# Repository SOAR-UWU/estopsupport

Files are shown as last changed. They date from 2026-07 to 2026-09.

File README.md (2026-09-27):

# Emergency-Stop Support Circuit
Driver Circuit for a Kilovac EV200 Contactor.
Takes two switch inputs which are expected to run at 5V with low current.

Theoretically, this can accept any relay or contactor that:
- has sufficiently high coil voltage, matched to the battery input, or uses a coil economiser
- has in-built back-emf suppression

# Variant: Integrated Automotive Relay
See relay branch for details - board designed to consolidate parts for the sake of compactness.

# Expected Operating Range

| Name | Value | Unit |
| --- | --- | ---- |
| Battery Voltage | 12 - 16.8 | V |
| Battery Current | ≤ 3 | A |
| Signal Voltage  | 5 | V |
| Signal Current  | 0 - 1 | A |
| Tap Voltage | 3.3 | V |
| Tap Current | 1.5 | A |
| Sense Resistor Voltage | 0.33 | V |
| Sense Resistor Voltage (Fault) | 5.2 | V |

# [BTS6163D PROFET](https://www.infineon.com/assets/row/public/documents/10/49/infineon-bts6163d-ds-en.pdf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)
This circuit is primarily based on the BTS6163 PROFET, which behaves like a P-type MOSFET.
It is chosen due to the fault protection capabilities - it will fail open.

## Sense Resistor
There is a 1 kOhm resistor on the right side of the board that indicates whether the BTS6163D PROFET is in a fault condition.
Fault conditions generally include: Short circuit, overtemperature, overload.

# Opto-isolation
The 5V Signal side (left) is opto-isolated from the Battery Voltage side (right).
Opto-coupler was chosen over a MOSFET such that the 5V side can control the higher voltage side without a risk of shorting battery voltage (16.8V) to the 5V rail.

# Split ground planes
If separate power sources are used for 5V and Battery, both sides will be totally decoupled.
This reduces electromagnetic interference - but is not important in this circuit, as it does not work with sensitive signals.

# Order Parameters
Material: FR-4
Layers: 2
Copper Weight: 1 oz

# Recommended Wiring
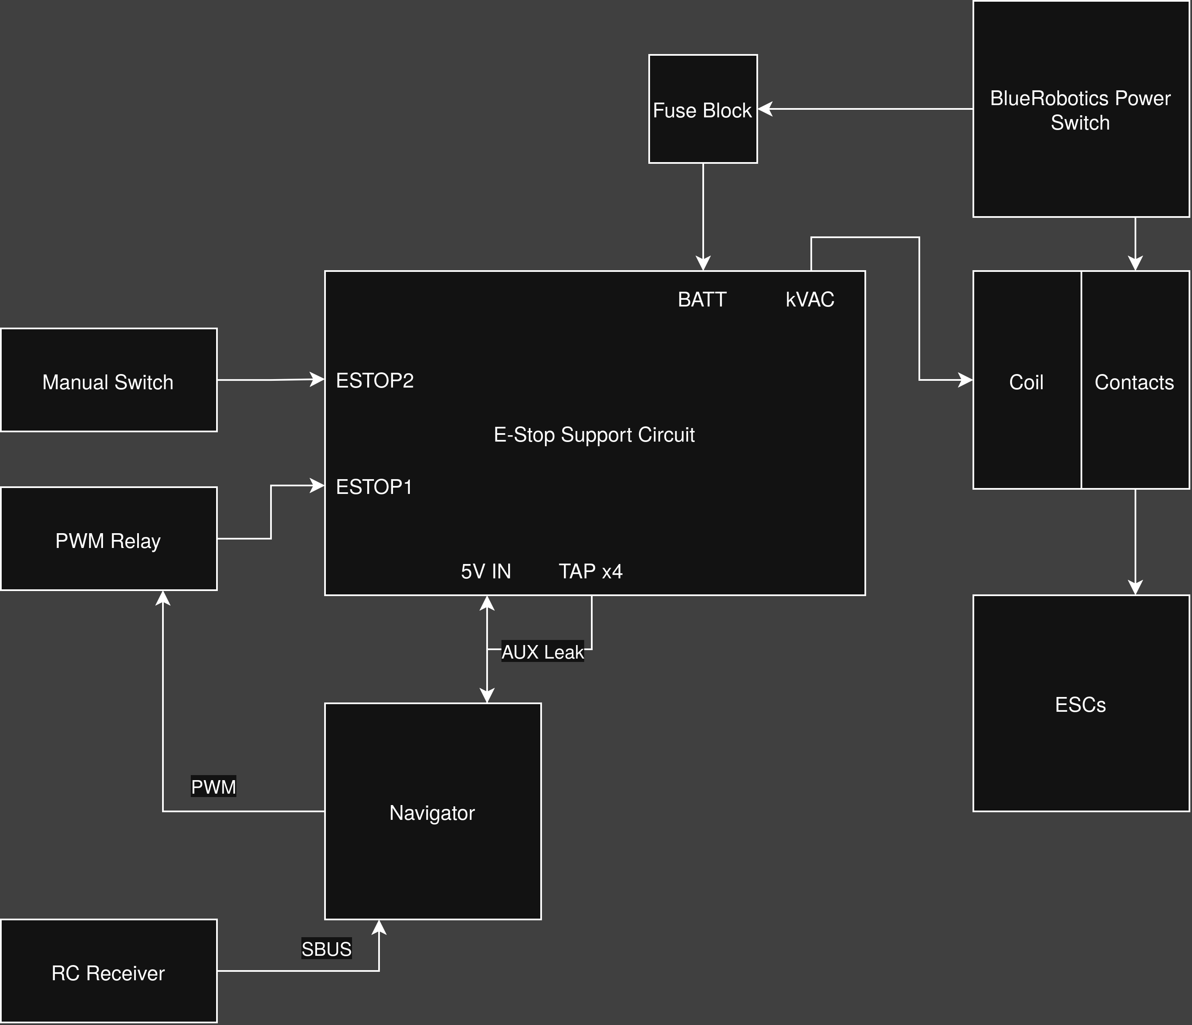
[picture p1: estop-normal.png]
normal

Normal Operation

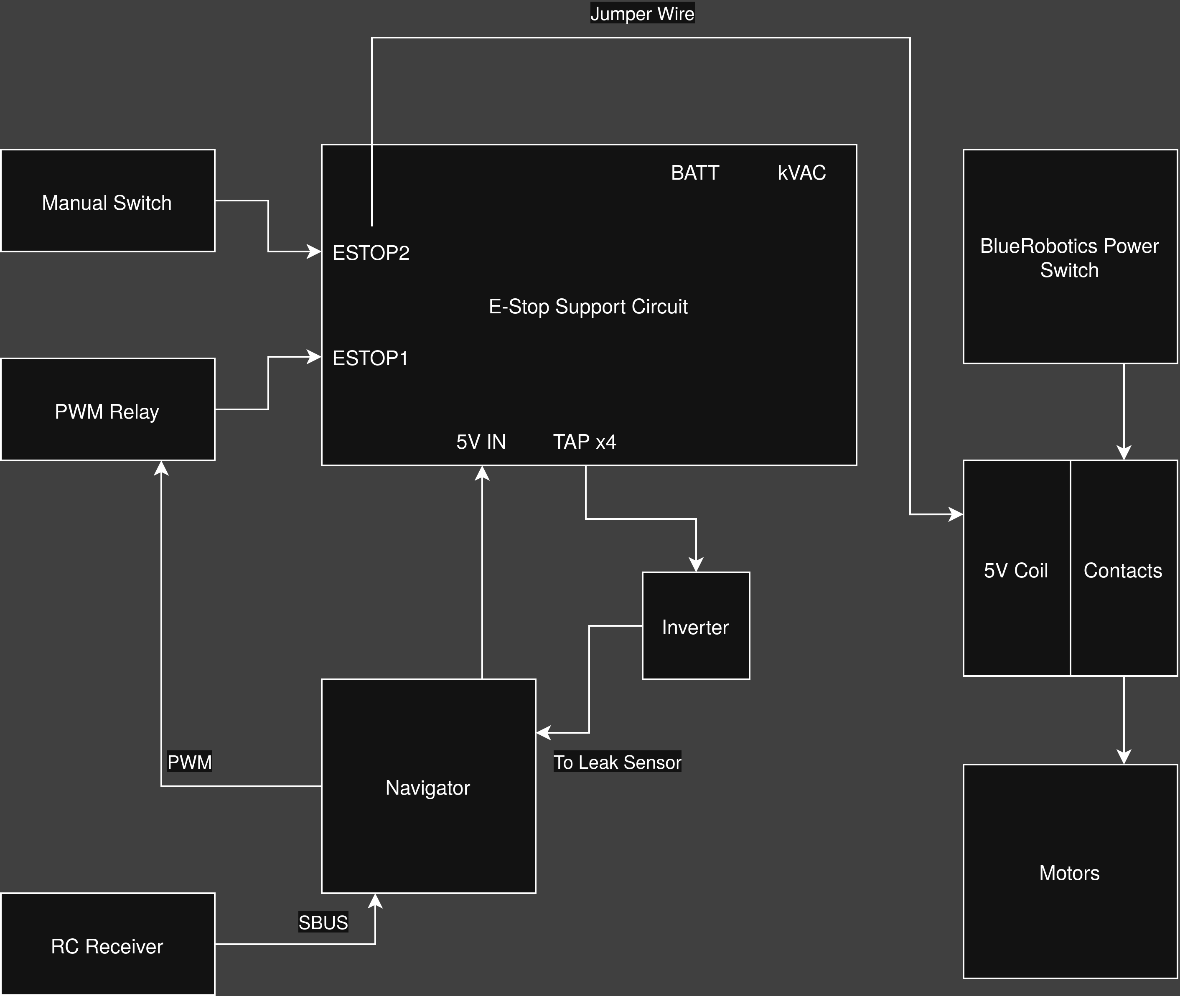
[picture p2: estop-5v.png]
5v

5V Relay Control

Battery voltage side is not used. This is because the PROFET has a threshold voltage of 5.5V.

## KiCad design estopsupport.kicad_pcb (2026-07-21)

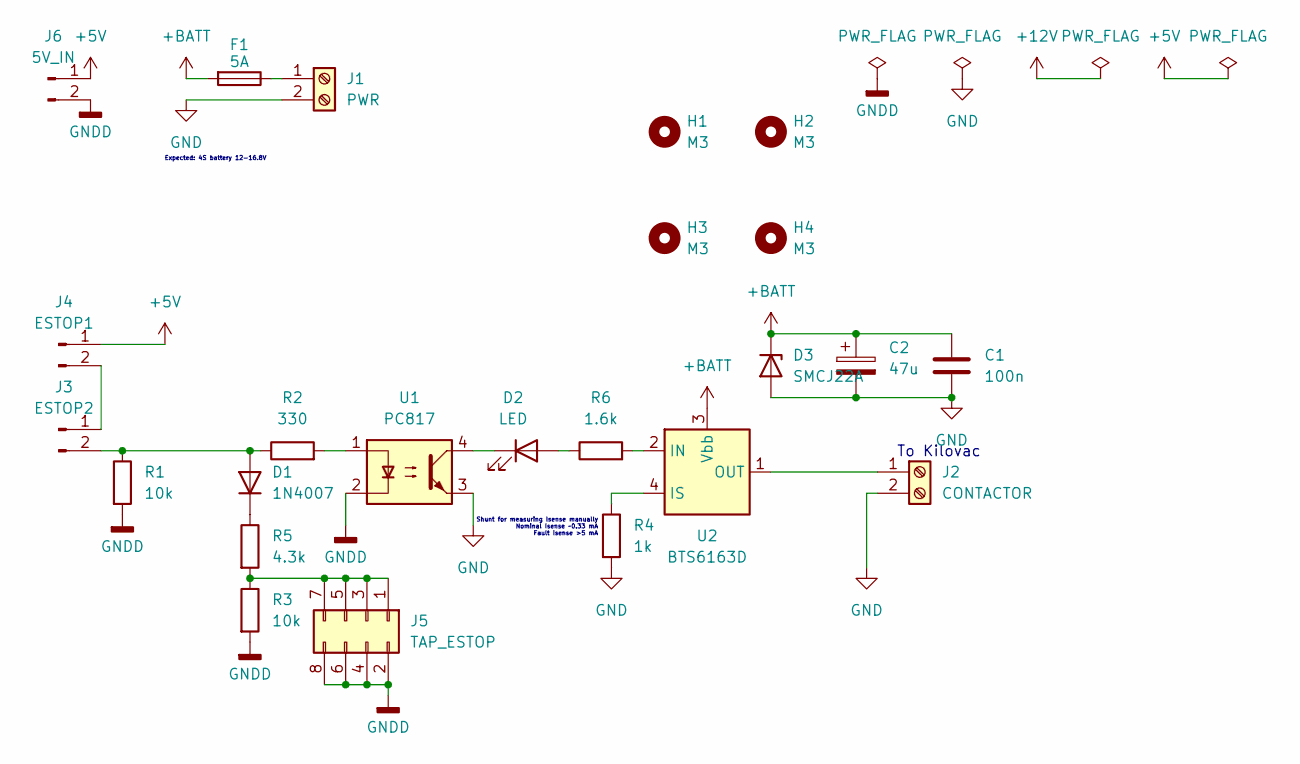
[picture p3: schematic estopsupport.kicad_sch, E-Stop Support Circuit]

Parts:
C1: 100n; C_1206_3216Metric; JLCPCB Part # C24497
C2: 47u; CP_Elec_6.3x5.4; JLCPCB Part # C48543040
D1: 1N4007; D_SMA; JLCPCB Part # C2909831
D2: LED; LED_D3.0mm
D3: SMCJ22A; D_SMC
F1: 5A; Fuse_1206_3216Metric_Pad1.42x1.75mm_HandSolder
H1, H2, H3, H4: M3; MountingHole_3.2mm_M3
J1: PWR; TerminalBlock_Phoenix_MKDS-1,5-2_1x02_P5.00mm_Horizontal
J2: CONTACTOR; TerminalBlock_Phoenix_MKDS-1,5-2_1x02_P5.00mm_Horizontal
J3: ESTOP2; PinHeader_1x02_P2.54mm_Horizontal
J4: ESTOP1; PinHeader_1x02_P2.54mm_Horizontal
J5: TAP_ESTOP; PinSocket_2x04_P2.54mm_Horizontal
J6: 5V_IN; PinHeader_1x02_P2.54mm_Horizontal
R1, R3: 10k; R_0603_1608Metric
R2: 330; R_0603_1608Metric
R4: 1k; R_Axial_DIN0204_L3.6mm_D1.6mm_P7.62mm_Horizontal
R5: 4.3k; R_0603_1608Metric
R6: 1.6k; R_0603_1608Metric
U1: PC817; DIP-4_W7.62mm; JLCPCB Part # C5350
U2: BTS6163D; TO-252-4; JLCPCB Part # C534821

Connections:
+5V: J4.1, J6.1
+BATT: C1.1, C2.1, D3.1 (K), F1.2, U2.3 (Vbb)
GND: C1.2, C2.2, D3.2 (A), J1.2, J2.2, R4.2, U1.3
GNDD: J5.2, J5.4, J5.6, J5.8, J6.2, R1.2, R3.2, U1.2
unnamed: D1.2 (A), J3.2, R1.1, R2.1
unnamed: D1.1 (K), R5.1
unnamed: D2.2 (A), R6.1
unnamed: D2.1 (K), U1.4
unnamed: F1.1, J1.1
unnamed: J2.1, U2.1 (OUT), U2.5 (OUT)
unnamed: J3.1, J4.2
unnamed: J5.1, J5.3, J5.5, J5.7, R3.1, R5.2
unnamed: R2.2, U1.1
unnamed: R6.2, U2.2 (IN)
unnamed: R4.1, U2.4 (IS)

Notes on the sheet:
Shunt for measuring Isense manually Nominal Isense ~0.33 mA Fault Isense >5 mA
To Kilovac
Expected: 4S battery 12-16.8V

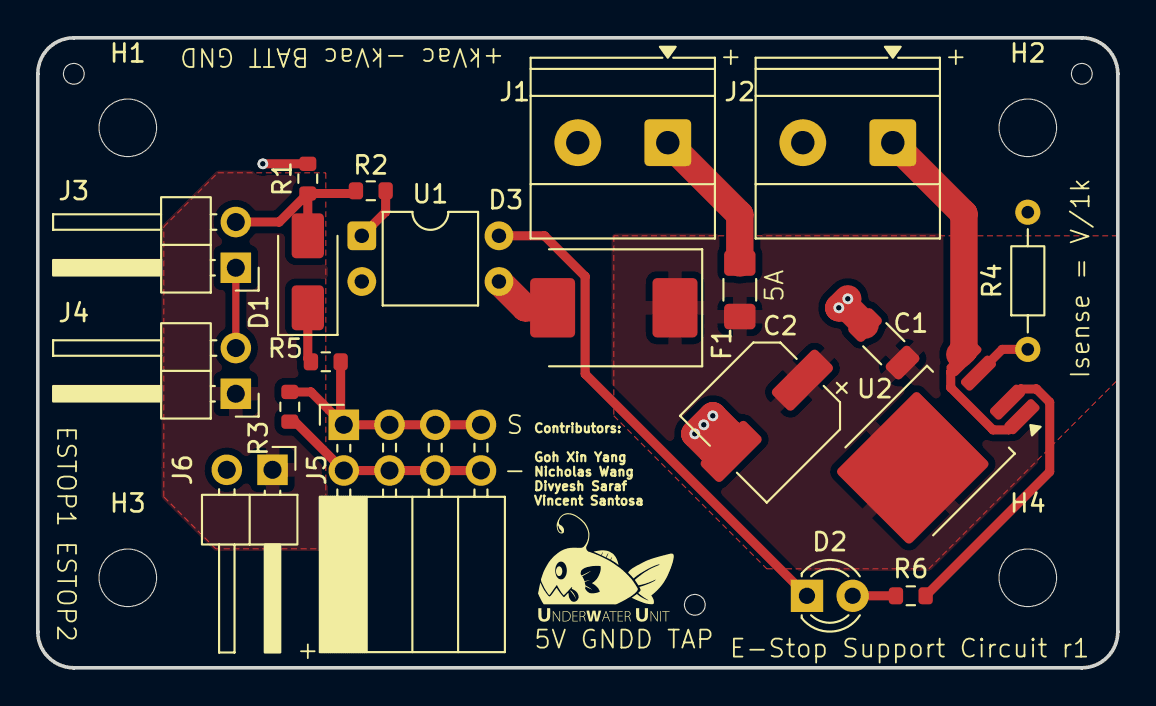
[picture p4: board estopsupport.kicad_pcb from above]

Board: 2 copper layers, 60.0 x 35.0 mm, 24 parts (0 on the bottom side), 15 nets.

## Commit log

2026-06-16 initial commit: only low side controlled and unsafe
    [estopsupport.kicad_pcb, estopsupport.kicad_sch]
2026-06-16 feat: add high side relay and suggestions from gemini
    [estopsupport.kicad_sch]
2026-06-23 feat: use a profet instead - simpler and more resistant to vibration. TBD: Connector footprint
    [estopsupport.kicad_sch]
2026-06-24 chore: finally settle on Phoenix Contact screw terminal
    [estopsupport.kicad_sch]
2026-06-24 refactor: don't rely on adapter board - just design for it to be manually serviced and checked via shunt resistor
    [estopsupport.kicad_sch]
2026-06-25 feat: routed pcb
    [estopsupport.kicad_pcb]
2026-06-26 refactor: use a tht resistor for the shunt - easier to probe and replace
    [estopsupport.kicad_pcb, estopsupport.kicad_sch]
2026-06-26 fix: silkscreen overlap
    [estopsupport.kicad_pcb]
2026-07-07 fix: shunt resistor value changed to datasheet recommendation
    [estopsupport.kicad_pcb, estopsupport.kicad_sch]
2026-07-07 feat: started BOM, added ground lines to tap
    [estopsupport.kicad_pcb, estopsupport.kicad_sch]
2026-07-15 feat: change to use battery voltage directly for powering the coil
    [estopsupport.kicad_pcb, estopsupport.kicad_sch]
2026-07-16 feat: include logo properly, reroute to use capacitors properly, add fuse
    [estopsupport.kicad_pcb, estopsupport.kicad_sch]
2026-07-17 fix: remove unneeded flyback for kilovac major rearrangement
    [estopsupport.kicad_pcb, estopsupport.kicad_sch]
2026-07-21 final adjustments for ordering
    [estopsupport.kicad_pcb, estopsupport.kicad_sch]
2026-09-04 doc: Add README for Emergency-Stop Support Circuit
    Added detailed documentation for the Emergency-Stop Support Circuit, including expected operating range, component specifications, and circuit behavior.
2026-09-27 fix: README - line about BATT side of board being unused was in the wrong place
2026-09-27 doc: README tweaks
    Reformatted the description for clarity and added bullet points for relay requirements.
2026-09-27 doc: add reference to relay branch
    Added section for Integrated Automotive Relay variant.
